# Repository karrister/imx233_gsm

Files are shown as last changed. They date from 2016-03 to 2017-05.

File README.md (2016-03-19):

IMX233 GSM
=============

This project started as my thesis project for the University (of applied sciences) of Helsinki. The project is about making a simple open source, Linux based cellular phone. In the heart of the device are an Olimex made Olinuxino (the original) IMX233 development board, connected over an application UART to a SIM900 GPRS GSM-development board. I will also connect a self-made keypad (1 button at first stage) and a self-made screen (1 LED indicator at first stage).

For now I have seized the PCB design for a board combining the two Chips on a shared board, as the final design did not meet the requirements for printing. I will publish the current PCB design files (kicad) here and also plan to continue the work to have a printed board eventually.

Currently I have created a 4.1.1 kernel, running with Debian Jessie on the CPU. The Software for interfacing the Hardware will be a set of Python scripts, communicating with the Chip, parsing the AT commands as well as controlling the custom keypad and screen.

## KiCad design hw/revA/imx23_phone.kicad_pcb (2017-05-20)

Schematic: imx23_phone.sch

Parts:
C1, C3: 10uF/6.3V
C2, C4, C5, C6, C7, C8, C9, C10, C12, C24, C29, C31, C33, C34, C46, C48, C49: 100nF
C11, C20, C23, C26, C28, C30, C32, C35, C36, C42, C43, C44, C45, C47, C50, C51, C54, C55: 22uF/6.3V
C13: 470uF
C14, C16, C17, C19, C25: 33pF
C15, C22: 10pF
C18: 4.7uF
C21: NC(10pF)
C27, C39: 1uF
C37, C38: 15pF
C40, C41: NC
C52, C53: 220uF/10V/105C
D1, D5: DIODESCH
D2: BAT54C
D3: LED
D4: AVALANCHE-SMBJ6.0A
J1: AUDIO_3.5
J2, J3: U.FL
J4: MICROSD_SIM_COMBO
J5: USB_MINI
L1: 22uH/1.5A/YS75/7x8mm
L2: FB0805/600R/2A
L3: 470nH/0805/1.76R/250mA
L4: FB0805/600R/200mA
P1: BATT
P2: EXT_GSM_POWER
P3: MIC_P
P4: MIC_N
P5: SPK_P
P6: SPK_GND
P7: RTC_VDD
P8: RTC_GND
P9: GSM_PWR
P10: SPK_N
P11: GSM_DBG_RX
P12: GSM_DBG_TX
P13: STATUS
P14: NETLIGHT
P15: CONN_4
P16: SIM_VPP
P17: LCD_D11
P18: I2C
P19: LCD_CS
P20: 5V_OUT
P21: GPIO4/LRADC0
P22: GPIO2
P23: GPIO3
P24: GPIO1
R1, R12, R14: 120
R2, R3, R23, R26: 1k/1%
R4: NC(0)
R5, R36: 0
R6, R7, R9, R10, R27, R29, R34: 10k
R8: 68
R11: 1k
R13, R15, R24, R43, R44, R45, R46: 4k7
R16: 10
R17, R35, R39, R42: 47k
R18: 0R
R19, R20, R21: 22
R22, R30, R31, R32: 100k
R25, R37, R38: 2k2
R28: 1M
R33: NA(47k)
R40, R41: NC(47k)
SW1: POWER
SW2: REC
T1: PMGD175XN
T2: BSV52
U1: FREESCALE-IMX233
U2: HY5DU121622D
U3: SMA_JACK
U4: SIM900
U5: LCD_NOKIA5110
X1: Q24.000MHz/HC-49SM/SMD/20ppm/20pF

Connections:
+2.5V: C1.1, C2.1, C3.1, C4.1, C5.1, C6.1, C7.1, C8.1, C9.1, C42.1, C44.1, C46.1, C48.1, R2.1, R27.1, U1.38 (VDDIO_EMIQ), U1.45 (VDDIO_EMI1), U1.53 (VDDIO_EMI2), U1.106 (VDDM/LRADC4), U2.1 (VDD1), U2.3 (VDDQ1), U2.9 (VDDQ2), U2.15 (VDDQ3), U2.18 (VDD2), U2.33 (VDD3), U2.55 (VDDQ4), U2.61 (VDDQ5)
+3.3V: C26.1, C28.1, C29.1, C43.1, C45.1, L3.2, P18.1, R24.2, R29.2, R30.2, R31.2, R32.2, R34.1, R35.2, R37.1, R38.1, R43.2, R44.2, R45.2, R46.2, U1.18 (VDDIO33_1), U1.92 (VDDIO33_3), U1.95 (DCDC_VDDIO), U5.6 (VCC)
+5V: C32.1, C34.1, C50.1, C51.1, L2.1, P20.1, U1.102 (VDD5V)
GND: C1.2, C2.2, C3.2, C4.2, C5.2, C6.2, C7.2, C8.2, C10.2, C11.2, C12.2, C13.2, C14.2, C15.2, C16.2, C17.2, C18.2, C19.2, C20.2, C21.2, C22.2, C23.2, C24.2, C25.2, C26.2, C28.2, C29.2, C30.2, C31.2, C32.2, C33.2, C34.2, C35.2, C36.2, C37.2, C38.2, C39.2, C40.2, C41.2, C42.2, C43.2, C44.2, C45.2, C46.2, C47.2, C48.2, C49.2, C50.2, C51.2, C52.2, C53.2, C54.2, C55.2, D4.1 (A), J2.2 (GND), J2.3 (GND), J3.2 (GND), J3.3 (GND), J4.G1 (GND), J4.G2 (GND), J4.G3 (GND), J4.S4 (GND), J4.T6 (VSS), J5.5 (GND), L4.1, P1.2 (PM), P4.1, P6.1, P8.1, P15.3, P18.4, R3.2, R17.2, R22.1, R25.1, R28.2, R33.1, R39.1, R40.1, R41.1, R42.1, T2.2 (E), U1.30 (VSSD1), U1.35 (VSSD2), U1.98 (DCDC_GND), U1.105 (VSSA4), U1.112 (VSSA1), U1.118 (VSSA2), U2.6 (VSSQ1), U2.12 (VSSQ2), U2.34 (VSS1), U2.48 (VSS2), U2.52 (VSSQ3), U2.58 (VSSQ4), U2.64 (VSSQ5), U2.66 (VSS3), U3.2 (GND), U3.3 (GND), U3.4 (GND), U3.5 (GND), U4.17 (GND), U4.18 (GND), U4.20 (MIC_N), U4.29 (GND), U4.39 (GND), U4.45 (GND), U4.46 (GND), U4.53 (GND), U4.54 (GND), U4.58 (GND), U4.59 (GND), U4.61 (GND), U4.62 (GND), U4.63 (GND), U4.64 (GND), U4.65 (GND), U5.8 (GND)
unnamed: R11.2, U4.1 (PWRKEY)
unnamed: P9.1, R11.1, T2.3 (C)
unnamed: R15.2, R17.1, T2.1 (B)
unnamed: R13.2, U4.4 (RI)
unnamed: P14.1, U4.52 (NETLIGHT)
unnamed: P13.1, U4.66 (STATUS)
unnamed: C41.1, J3.1 (SIG), R18.2
unnamed: C40.1, R18.1, U4.60 (RF_ANT)
unnamed: J2.1 (SIG), U3.1 (RF)
unnamed: C18.1, P7.1, U4.26 (VRTC)
unnamed: C35.1, C36.1, D1.2 (K), U1.101 (VDD4P2)
unnamed: R15.1, U1.82 (GPMI_CE0N)
unnamed: R13.1, U1.81 (GPMI_CE1N)
unnamed: J1.2 (L), R14.2, U1.113 (HPL)
unnamed: J1.3 (R), R12.2, U1.109 (HPR)
unnamed: J1.1 (GND), R12.1, R14.1, U1.111 (HP_VGND)
unnamed: P2.1, R4.1
unnamed: J4.T8 (DAT1), R30.1, U1.85 (SSP1_DATA1/I2C_SCL/JTAG_TCLK)
unnamed: J4.S6 (I/O), R21.2
unnamed: P12.1, U4.27 (DEBUG_TXD)
unnamed: P11.1, U4.28 (DEBUG_RXD)
unnamed: J4.S2 (RST), R19.2
unnamed: R20.1, U4.32 (SIM_CLK)
unnamed: J4.S3 (CLK), R20.2
unnamed: R21.1, U4.31 (SIM_DATA)
unnamed: J4.S1 (VCC), U4.30 (SIM_VDD)
unnamed: R35.1, U1.14 (LCD_RS)
unnamed: J4.T1 (DAT2), R32.1, U1.86 (SSP1_DATA2/I2C_SDA/JTAG_RTCK)
unnamed: J4.T7 (DAT0), R31.1, U1.84 (SSP1_DATA0/SPI1_MISO/JTAG_TDI)
unnamed: J4.T3 (CMD), R29.1, U1.83 (SSP1_CMD/SPI1_MOSI/JTAG_TDO)
unnamed: J4.T5 (CLK), U1.90 (SSP1_SCK/SPI1_SCK/JTAG_TRST)
unnamed: J4.T2 (CD/DAT3), R28.1, U1.87 (SSP1_DATA3/SPI1_SS#/JTAG_TMS)
unnamed: R7.2, T1.4 (S2), U4.10 (RXD)
unnamed: R9.2, T1.6 (D1), U1.128 (I2C_SDA/GPMI_CE2N/AUART1_RX)
unnamed: R6.1, T1.1 (S1), U4.9 (TXD)
unnamed: R10.2, T1.3 (D2), U1.127 (I2C_SCL/GPMI_RDY2/AUART1_TX)
unnamed: R6.2, R7.1, T1.2 (G1), T1.5 (G2), U4.15 (VDD_EXT)
unnamed: R19.1, U4.33 (SIM_RST)
unnamed: C27.1, U4.21 (SPK_P)
unnamed: C14.1, P3.1, R8.1
unnamed: C17.1, R8.2, U4.19 (MIC_P)
unnamed: R34.2, SW2.2
unnamed: R36.1, U1.27 (GPMI_D04/LCD_D12/SSP2_DATA4)
unnamed: D2.1 (Anode), U1.125 (PWM0/ROTARYA/DUART_RX)
unnamed: D2.3 (cathode), R24.1
unnamed: D2.2 (AK), P15.1
unnamed: R40.2, R44.1, U1.3 (LCD_D01)
unnamed: R33.2, U1.7 (LCD_D05)
unnamed: C33.1, SW1.2, U1.120 (VDDXTAL)
unnamed: R26.2, U1.119 (PSWITCH)
unnamed: R42.2, R46.1, U1.5 (LCD_D03)
unnamed: R41.2, R45.1, U1.4 (LCD_D02)
unnamed: R39.2, R43.1, U1.2 (LCD_D00)
unnamed: R22.2, R23.1, R26.1, R36.2, SW1.1, SW2.1
unnamed: C49.1, R23.2
unnamed: P22.1, U1.17 (LCD_DOTCK/GPMI_RDY3)
unnamed: J5.S (SHIELD), L4.2
unnamed: P21.1, U1.108 (LRADC0)
unnamed: P23.1, U1.20 (GPMI_ALE/LCD_D17)
unnamed: P24.1, U1.34 (GPMI_WPN)
unnamed: P10.1, U4.22 (SPK_N)
unnamed: P17.1, U1.25 (GPMI_D03/LCD_D11/SSP2_DATA3)
unnamed: R4.2, R5.1, U4.55 (VBAT), U4.56 (VBAT), U4.57 (VBAT)
unnamed: P19.1, U1.32 (GPMI_RDY0/SSP2_DETECT), U5.2 (CS)
unnamed: J4.S5 (VPP), P16.1
unnamed: C22.1, L1.1, U1.99 (DCDC_LP)
unnamed: C38.1, U1.121 (XTALO), X1.1
unnamed: D3.2 (K), R25.2
unnamed: D3.1 (A), U1.88 (SSP1_DETECT/GPMI_CE3N/USB_ID)
unnamed: P15.4, U1.89 (DEBUG)
unnamed: P15.2, U1.126 (PWM1/ROTARYB/DUART_TX)
unnamed: C21.1, L1.2, U1.97 (DCDC_LN1)
unnamed: C39.1, U1.117 (VAG)
unnamed: C20.1, C30.1, C31.1, C47.1, U1.1 (VDDD1), U1.93 (VDDD3), U1.94 (DCDC_VDDD)
unnamed: C23.1, C24.1, U1.96 (DCDC_VDDA), U1.110 (VDDA1)
unnamed: U1.9 (LCD_D07), U5.1 (RST)
unnamed: U1.8 (LCD_D06), U5.3 (DC)
unnamed: U1.91 (PWM2/GPMI_RDY3), U5.7 (LIGHT)
unnamed: U1.33 (GPMI_WRN/SSP2_SCK), U5.5 (CLK)
unnamed: U1.21 (GPMI_RDY1/SSP2_CMD), U5.4 (DIN)
unnamed: J5.3 (D+), U1.124 (USB_DP)
unnamed: D5.1 (A), J5.1 (VBUS)
unnamed: C52.1, C53.1, D4.2 (K), D5.2 (K), L2.2
unnamed: P18.3, R37.2, U1.15 (LCD_HSYNC/I2C_SDA)
unnamed: P18.2, R38.2, U1.11 (LCD_ENABLE/I2C_SCL)
unnamed: J5.2 (D-), U1.123 (USB_DM)
unnamed: C54.1, C55.1, J4.T4 (VDD), L3.1
unnamed: C9.2, C10.1, R2.2, R3.1, U2.49 (VREF)
unnamed: C15.1, C16.1, C19.1, P5.1, R16.1
unnamed: C25.1, C27.2, R16.2
unnamed: U1.72 (EMI_A04), U2.35 (A4)
unnamed: U1.51 (EMI_D08), U2.54 (DQ8)
unnamed: U1.78 (EMI_CKE), U2.44 (CKE)
unnamed: U1.60 (EMI_D14), U2.63 (DQ14)
unnamed: U1.62 (EMI_RASN), U2.23 (/RAS)
unnamed: U1.50 (EMI_D07), U2.13 (DQ7)
unnamed: U1.58 (EMI_D13), U2.62 (DQ13)
unnamed: U1.64 (EMI_A12), U2.42 (A12)
unnamed: U1.73 (EMI_A03), U2.32 (A3)
unnamed: U1.61 (EMI_CASN), U2.22 (/CAS)
unnamed: U1.40 (EMI_DQS1), U2.51 (UDQS)
unnamed: U1.54 (EMI_D10), U2.57 (DQ10)
unnamed: U1.55 (EMI_D11), U2.59 (DQ11)
unnamed: U1.68 (EMI_A08), U2.39 (A8)
unnamed: U1.76 (EMI_A00), U2.29 (A0)
unnamed: U1.69 (EMI_A07), U2.38 (A7)
unnamed: U1.66 (EMI_A10), U2.28 (A10/AP)
unnamed: U1.65 (EMI_A11), U2.41 (A11)
unnamed: U1.56 (EMI_DQM1), U2.47 (UDM)
unnamed: U1.70 (EMI_A06), U2.37 (A6)
unnamed: U1.80 (EMI_BA1), U2.27 (BA1)
unnamed: U1.52 (EMI_D09), U2.56 (DQ9)
unnamed: U1.71 (EMI_A05), U2.36 (A5)
unnamed: U1.59 (EMI_D15), U2.65 (DQ15)
unnamed: U1.74 (EMI_A02), U2.31 (A2)
unnamed: U1.77 (EMI_WEN), U2.21 (/WE)
unnamed: U1.49 (EMI_D06), U2.11 (DQ6)
unnamed: U1.57 (EMI_D12), U2.60 (DQ12)
unnamed: U1.67 (EMI_A09), U2.40 (A9)
unnamed: U1.75 (EMI_A01), U2.30 (A1)
unnamed: U1.46 (EMI_DQM0), U2.20 (LDM)
unnamed: U1.48 (EMI_D05), U2.10 (DQ5)
unnamed: U1.41 (EMI_D00), U2.2 (DQ0)
unnamed: U1.79 (EMI_BA0), U2.26 (BA0)
unnamed: R27.2, U1.63 (EMI_CE0N), U2.24 (/CS)
unnamed: R1.2, U1.37 (EMI_CLKN), U2.46 (/CK)
unnamed: R1.1, U1.36 (EMI_CLK), U2.45 (CK)
unnamed: U1.47 (EMI_D04), U2.8 (DQ4)
unnamed: U1.44 (EMI_D03), U2.7 (DQ3)
unnamed: U1.42 (EMI_D02), U2.5 (DQ2)
unnamed: U1.43 (EMI_D01), U2.4 (DQ1)
unnamed: U1.39 (EMI_DQS0), U2.16 (LDQS)
unnamed: C11.1, C12.1, C13.1, D1.1 (A), P1.1, R5.2, R9.1, R10.1, U1.100 (DCDC_BATTERY), U1.103 (BATT)
unnamed: C37.1, U1.122 (XTALI), X1.2

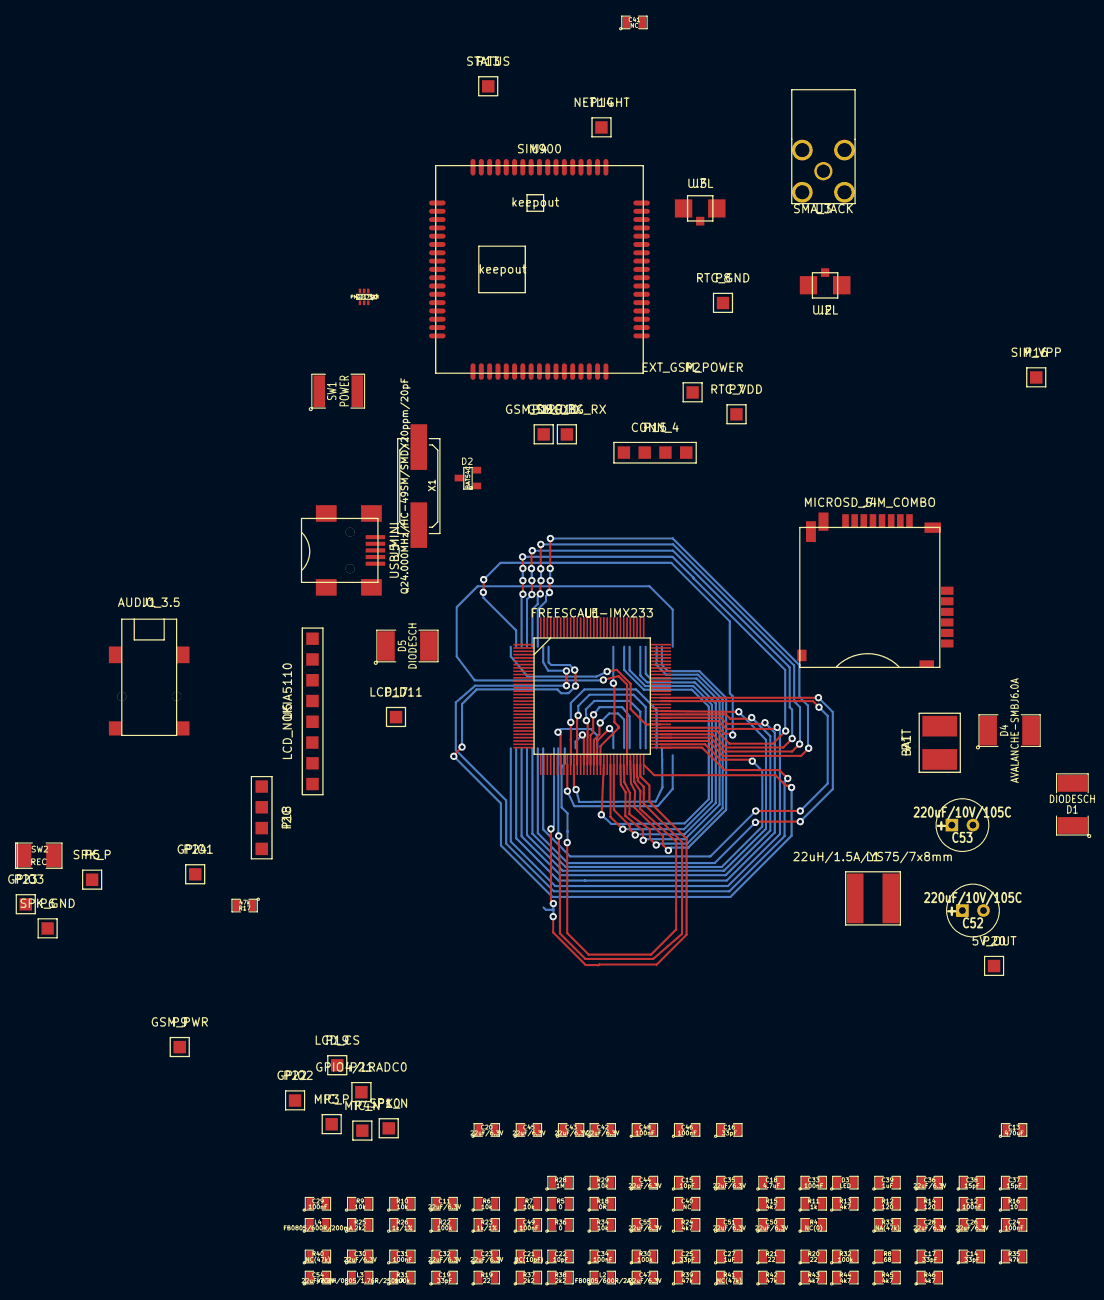
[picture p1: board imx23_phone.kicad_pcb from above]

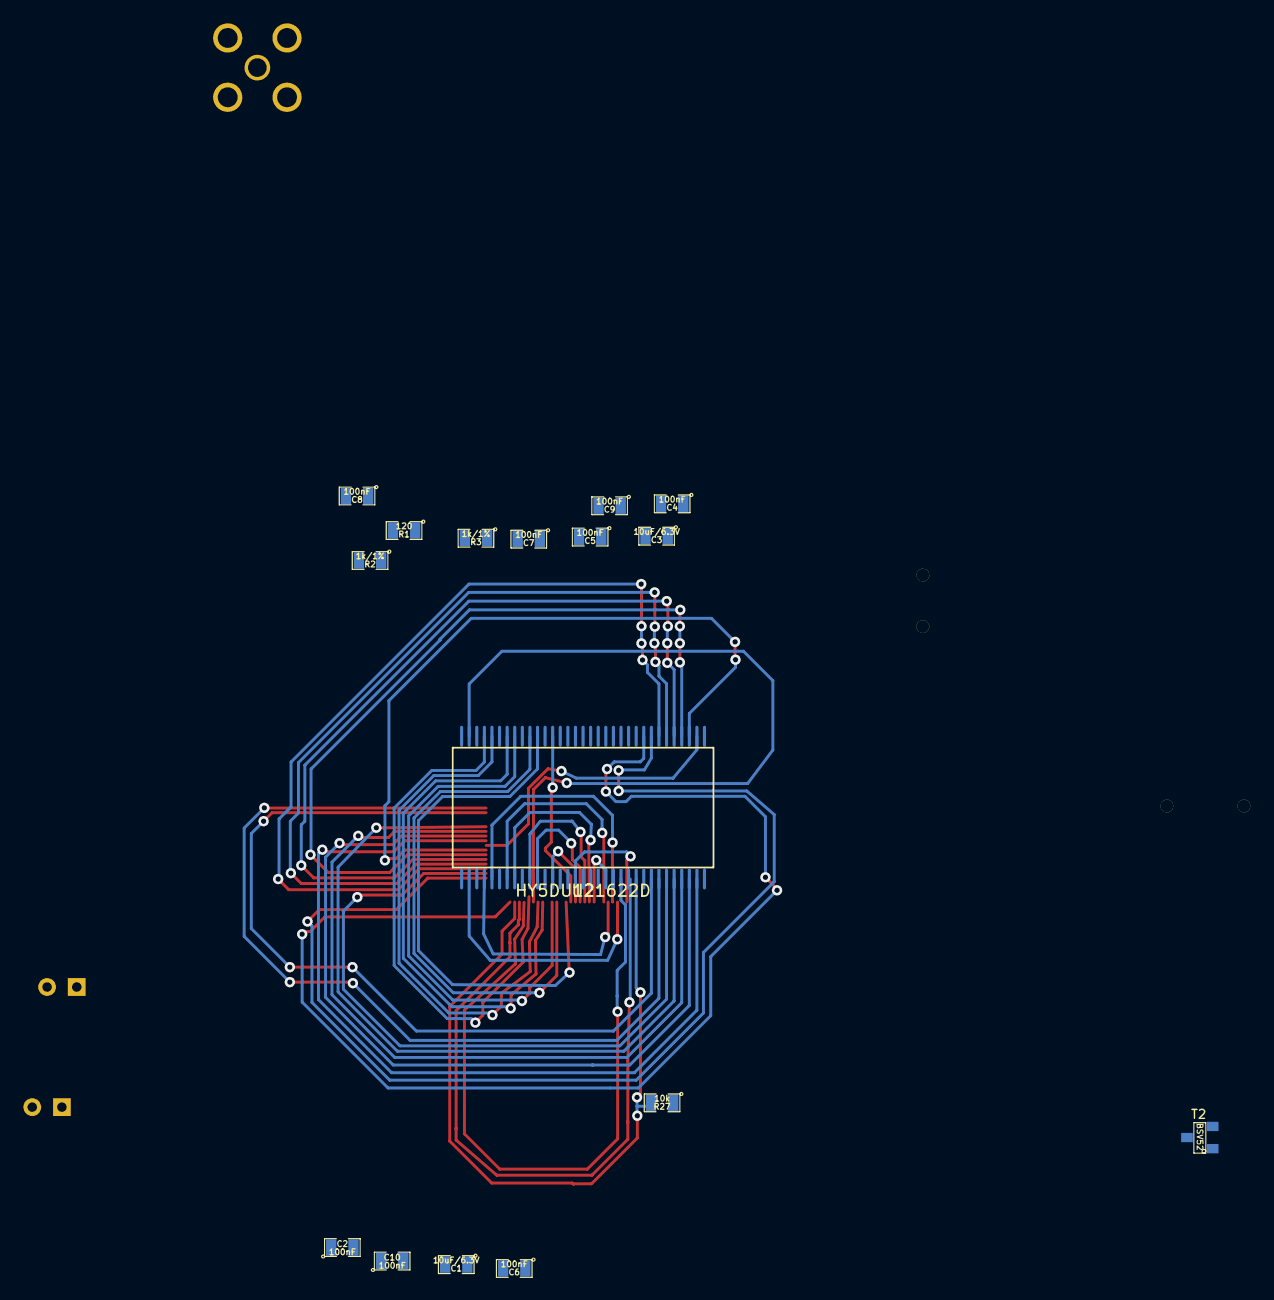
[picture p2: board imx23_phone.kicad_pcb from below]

Board: 2 copper layers, 149 parts (16 on the bottom side), 137 nets.

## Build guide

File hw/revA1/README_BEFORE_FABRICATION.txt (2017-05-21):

Please note that this design did not pass the checks in Seeedstudio PCB fabrication service. This was their comment:

"The distance between circuit is 0.05mm, it is too small for fabrication.  We suggest to decrease the 0.25mm circuit into 0.15mm."

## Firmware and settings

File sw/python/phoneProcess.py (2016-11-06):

#!/usr/bin/python
# Author: 
#	Karri Kivela
#
# Description:
#	This is the main file for the Python mobile phone application.
# This file is ran and manages the interfacing of the Hardware as
# well as the other Python components.

from modemATParser import ATParser
from keyPad import Keypad
from busDriver import BusDriver
from screen import Screen
from SIM900 import SIM900
from actionParser import ActionParser
from logger import Logger

def mainPhoneProcess(screen, keypad, bus, modem, logger):

	parser = ATParser(screen, keypad, bus, modem, logger)
	actionParser = ActionParser(screen, keypad, bus, modem, logger)
	noErrorDetected = True
	
	logger.pushLogMsg("Entering GSM main loop")

	while noErrorDetected == True:

		if modem.isChipInErrorState() == True:
			noErrorDetected = False

		if keypad.isUserActionWaiting() == True:
			userAction = keypad.getUserAction()
			actionParser.parseAction(userAction, parser)
		
		rawATCommand = bus.syncRead()
		
		parsedAction = parser.parseATCommand(rawATCommand)
		actionParser.parseAction(parsedAction, parser)

		logger.pushLogMsg("DEBUG: Main loop", 255)
	#Loop while noErrorDetected
	
	print "DEBUG: Exit main application"


def phoneStart():

	logger = Logger()
	
	logger.pushLogMsg("Starting GSM main process")

	bus = BusDriver(logger)

	while bus.isBusInitialized() == False:

		if bus.isBusInErrorState() == True:
			#Well, this was unexpected... We should return
			#from the app. Or maybe attempt a reset?
			logger.pushLogMsg("Init: Bus error!")
			return

	modem = SIM900(bus, logger) #Constructor starts the Chip init

	while modem.isChipInitialized() == False:
		
		if modem.isChipInErrorState() == True:
			#Well, this was unexpected... We should return
			#from the app. Or maybe attempt a reset?
			logger.pushLogMsg("Init: Chip error!")
			return

	keypad = Keypad(logger)
	if keypad.isInErrorState() == True:
		logger.pushLogMsg("Init: Keypad error!")
		return

	screen = Screen(logger)
	if screen.isInErrorState() == True:
		logger.pushLogMsg("Init: Screen error!")
		return

	#Init is complete, turn into the main part of the app
	#This call will be blocking for the lifetime of the app
	#and return only after an error was detected
	mainPhoneProcess(screen, keypad, bus, modem, logger)
	
	
if __name__ == "__main__":
	phoneStart()

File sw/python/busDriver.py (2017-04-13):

#!/usr/bin/python
# Author: 
#	Karri Kivela
#
# Description:
#	This is the comms bus driver, in
# this case the UART driver that takes
# care of communication with the Chip.

import serial

READ_TIMEOUT_SECS = 2
BAUDRATE = 19200
#Serial has different pointer in different OS and board
#SERIAL_DEV_NAME = "COM20" #Windows
#SERIAL_DEV_NAME = "/dev/ttyAPP0" #Linux imx233
SERIAL_DEV_NAME = "/dev/ttyUSB0" #FTDI USB serial

class BusDriver:

	isBusInitialized = False
	isBusInErrorState = False
	busContext = serial.Serial()

	#Currently the constructor will do a blocking init,
	#returning to the user only after Chip is up
	def __init__(self, log, isBlockingInit = True):
		self.log = log
		busContext = self.openBus()
		#TODO: remove this state change if implement non Blocking constructor
		isBusInitialized = True

	def isBusInitialized(self):
		return self.isBusInitialized

	def isBusInErrorState(self):
		return self.isBusInErrorState
		
	def openBus(self):
		try:
			self.busContext = serial.Serial()
			self.busContext.port = SERIAL_DEV_NAME
			self.busContext.timeout = READ_TIMEOUT_SECS
			self.busContext.baudrate = BAUDRATE
			self.busContext.open()
			isBusInitialized = True
		except: #serial.serialutil.SerialException:
			self.log.pushLogMsg("We got an exception attempting to open the serial!")
			self.closeBus()
			return
		
	def closeBus(self):
		isBusInitialized = False
		self.busContext.close()

	#Blocking read
	def syncRead(self):
	
		if self.isBusInitialized() == False or self.isBusInErrorState() == True:
			return
	
		try:
			#time.sleep(READ_TIMEOUT_SECS)
			busContext_string = self.busContext.readline()
			
			if isinstance(busContext_string, str):
				self.log.pushLogMsg("UART_R: " + busContext_string, 255)
		except: #serial.serialutil.SerialException:
			self.log.pushLogMsg("We got an exception from the serial!")
			self.closeBus()
			return
			
		return busContext_string

	#Blocking write
	def syncWrite(self, uartString):
		
		if self.isBusInitialized() == False or self.isBusInErrorState() == True:
			return
			
		if isinstance(uartString, str):
			self.log.pushLogMsg("UART_W: " + uartString, 255)
			
		try:
			self.busContext.write(uartString)
		except: #serial.serialutil.SerialException:
			self.log.pushLogMsg("We got an exception from the serial!")
			self.closeBus()
			return

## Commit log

2016-03-19 UART write stub *Bus driver write stub function
2016-08-29 Python framework works *Very basic python framework is now running
2016-11-06 More integration *Fixed reading HW event flow *Fixed reading user event flow *Fixing logger *Misc fixes and integration
    [SIM900.py, actionParser.py, busDriver.py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]
2016-11-12 Exception handling *Fixed exception handling (linux) *Modified the priviliges - now able to run python files
    [SIM900.py, actionParser.py, busDriver.py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]
2016-11-12 Some HW mocks *Mock for button GPIO *Mock for screen LED
2016-11-14 Fixing debug prints *Fixed some debug prints to not run if no string provided
    [busDriver.py]
2017-04-13 Integration with serial port on Linux *Bus driver integration for Linux USB serial port with modem *AT parser integration
2017-04-22 Add filesystem path to HW GPIO *Adding filesystem path for the specific GPIO for LED and switch on GSM board
2017-04-22 Adding version file *Adding a version file to identify script version on the device
2017-05-20 Adding PCB design files
    Adding PCB design files, from 2014.
    [imx23_phone-B_Cu.gbl, imx23_phone-B_Mask.gbs, imx23_phone-B_SilkS.gbo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]
2017-05-21 Adding a note for PCB RevA1
2018-03-03 Adding state module
    Adding state module for each SW module to know the state of the device
